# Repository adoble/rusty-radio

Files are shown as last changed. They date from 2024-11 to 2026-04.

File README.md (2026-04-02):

# Rusty Radio

An embedded internet radio written in Rust.

> **⚠️ Work In Progress**
>
> This project is under active development. Features, hardware, and software may change frequently. 

## Supported Formats

Rusty Radio currently supports:
- MP3
- AAC
- M3U

## System Diagram



## Hardware
 - For the radio uses the Seeed Studio [XIAO ESP32C-C3](https://wiki.seeedstudio.com/XIAO_ESP32C3_Getting_Started/) for its external antenna, making the radio independent of the enclosure.
 - For the user interface (display, tuning knob and preset buttons) uses another XIAO ESP32-C3 which communicates over an UART interface with the radio processor. 
   This approach was chosen as using C3 (or for that matter, a S3) for both the radio and the display led to memory issues.  
- Uses the VS1053 chip to decode the streamed audio.
- Schematics are created using KiCad 9.0.

## Software Architecture

- Built with `esp-hal` and [Embassy](https://dev.to/theembeddedrustacean/embassy-on-esp-getting-started-27fi) for async task scheduling.
- Project scaffolded using `cargo generate esp-rs/esp-template`. See the [GitHub repo](https://github.com/esp-rs/esp-template). The software project root is `controller`.

## Development Notes

- Embassy code examples are referenced from [esp-hal examples](https://github.com/esp-rs/esp-hal/tree/main/examples/src/bin).
- For more on Embassy, see the [Embassy Book](https://embassy.dev/book/).

---

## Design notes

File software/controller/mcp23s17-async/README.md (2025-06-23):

# Async MCP23S17 driver





An asynchronous driver for the MCP23S17 I/O expander which is accessed over an SPI bus.

## Example usage

```rs
// spi_device implements the SpiDevice trait from embedded_hal_async >= 1.0.0
// The hardware address corresponds to the way the pins A0, A1, A2 are physically connected
let mut mcp23s17 = mcp23s17_async::Mcp23s17::new(spi_device, 0b000).await.ok().unwrap();

// Configure pin GPA0 as an output
mcp23s17.pin_mode(0, mcp23s17_async::PinMode::Output).await.ok().unwrap();
// Set pin GPA0 high
mcp23s17.set_high(0);

// Configure pin GPA1 as an pullup input
mcp23s17.pin_mode(1, mcp23s17_async::PinMode::InputPullup).await.ok().unwrap();
// Read GPA1's level
let is_high = mcp23s17.read(1).await.ok().unwrap();
```

## Example implementation of the SpiDevice trait

```rs
// Assuming the SpiBus trait is implemented for Spi

spi_device = MySpiDevice::new(spi, cs);

struct MySpiDevice {
    spi: Spi,
    cs: SpiCsPin,
}

impl MySpiDevice{
    fn new(spi: Spi, mut cs: SpiCsPin) -> MySpiDevice {
        // IMPORTANT, otherwise MCP23S17 might not work
        cs.set_high();

        MySpiDevice { spi, cs }
    }
}

impl embedded_hal_async::spi::SpiDevice for MySpiDevice {
    async fn transaction(
        &mut self,
        operations: &mut [embedded_hal_async::spi::Operation<'_, u8>],
    ) -> Result<(), Self::Error> {  
        for operation in operations {
            match operation {
                embedded_hal_async::spi::Operation::DelayNs(_) => {}
                _ => {
                    self.cs.set_low();
                }
            }
            match operation {
                embedded_hal_async::spi::Operation::Read(words) => {
                    let _ = embedded_hal_async::spi::SpiBus::read(&mut self.spi, words).await;
                }
                embedded_hal_async::spi::Operation::Write(words) => {
                    let _ = embedded_hal_async::spi::SpiBus::write(&mut self.spi, words).await;
                }
                embedded_hal_async::spi::Operation::Transfer(read, write) => {
                    let _ = embedded_hal_async::spi::SpiBus::transfer(&mut self.spi, read, write).await;
                }
                embedded_hal_async::spi::Operation::TransferInPlace(words) => {
                    let _ = embedded_hal_async::spi::SpiBus::transfer_in_place(&mut self.spi, words).await;
                }
                embedded_hal_async::spi::Operation::DelayNs(ns) => {
                    delay_us(*ns / 1000).await;
                }
            }
            match operation {
                embedded_hal_async::spi::Operation::DelayNs(_) => {}
                _ => {
                    self.cs.set_high();
                }
            }                   
        }
        Ok(())
    }
}

impl embedded_hal_async::spi::ErrorType for MySpiDevice {
    type Error = Infallible;
}

impl core::fmt::Debug for MySpiDevice {
    fn fmt(&self, f: &mut core::fmt::Formatter<'_>) -> core::fmt::Result {
        write!(f, "MySpi")
    }
}
```

## Acknowledgements

Many of the documentation comments in this library are taken direct from the
[MCP23S17 datasheet](https://www.microchip.com/en-us/product/MCP23S17) and are
© 2005-2022 Microchip Technology Inc. and its subsidiaries.

Inspired by this [Arduino MCP23S17 Library](https://github.com/dreamcat4/Mcp23s17)
and the [RPPAL MCP23S17 Library](https://github.com/solimike/rppal-mcp23s17/)

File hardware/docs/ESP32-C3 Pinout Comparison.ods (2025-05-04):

Rusty Radio
Signal | ESP32-C3-DevKit-M1 |  | XIAO ESP32C3
 | Pins used |  |  |  | Maybe use
 | GPIO | 1 | GPIO | !!! | 3
 | GPIO | 2 |  | 2
 | GPIO
 | GPIO | 5 |  | 5
 | GPIO | 6 |  | 6
 | GPIO | 7 |  | 7
 | GPIO | 8 |  | 8
 | GPIO | 9 |  | 9
 | GPIO | 10 |  | 10
 | GPIO | 20 |  | !!! | 4

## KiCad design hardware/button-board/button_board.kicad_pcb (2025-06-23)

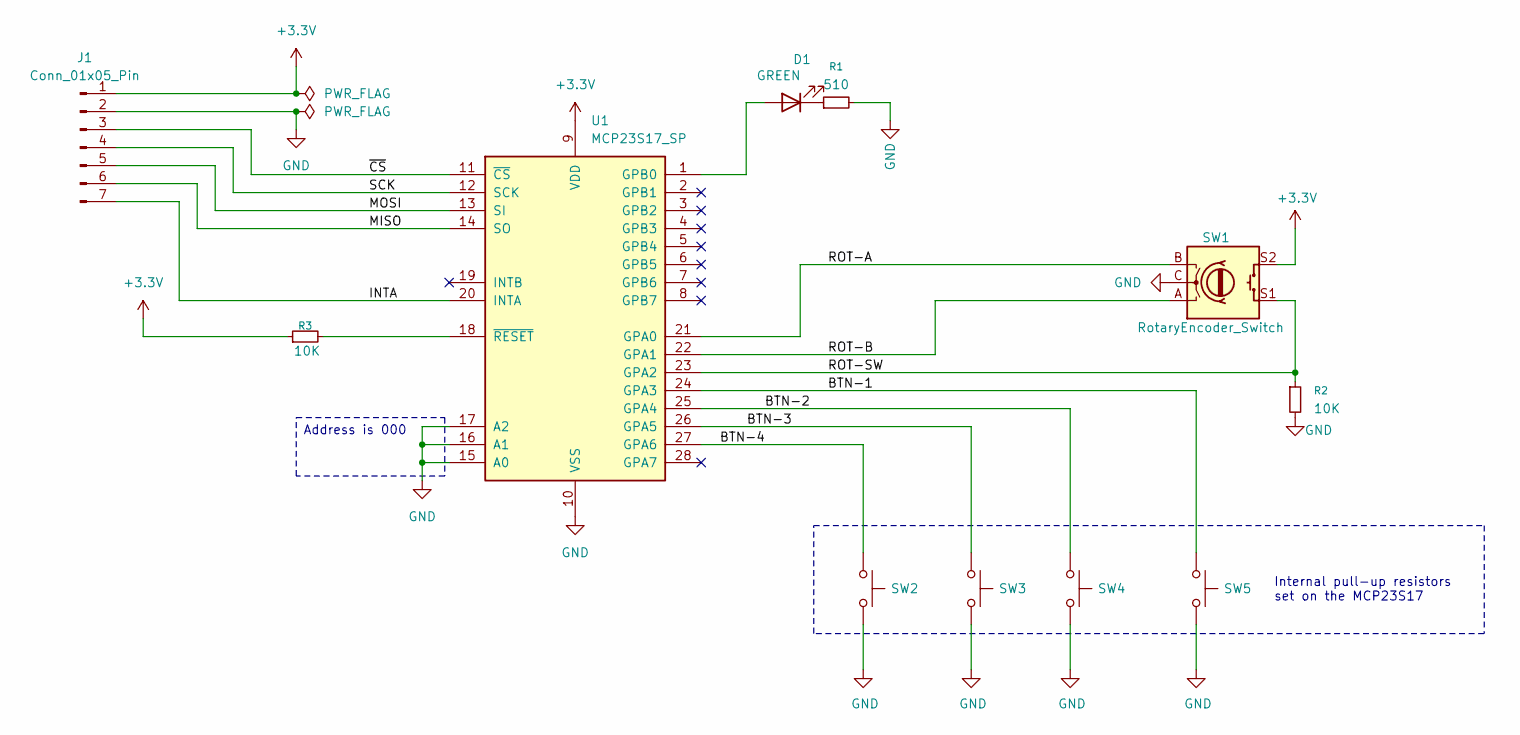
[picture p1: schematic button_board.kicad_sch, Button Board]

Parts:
D1: GREEN; D_T-1_P2.54mm_Vertical_AnodeUp
J1: Conn_01x05_Pin; PinHeader_1x07_P2.54mm_Vertical
R1: 510; R_Axial_DIN0207_L6.3mm_D2.5mm_P5.08mm_Vertical
R2, R3: 10K; R_Axial_DIN0207_L6.3mm_D2.5mm_P5.08mm_Vertical
SW1: RotaryEncoder_Switch; RotaryEncoder_Alps_EC11E-Switch_Vertical_H20mm
SW2, SW3, SW4, SW5: SW_Push; SW_Tactile_Straight_KSA0Axx1LFTR
U1: MCP23S17_SP; DIP-28_W7.62mm

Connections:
+3.3V: J1.1, R3.1, SW1.S2, U1.9 (VDD)
/BTN-1: SW5.1, U1.24 (GPA3)
/BTN-2: SW4.1, U1.25 (GPA4)
/BTN-3: SW3.1, U1.26 (GPA5)
/BTN-4: SW2.1, U1.27 (GPA6)
/INTA: J1.7, U1.20 (INTA)
/MISO: J1.6, U1.14 (SO)
/MOSI: J1.5, U1.13 (SI)
/ROT-A: SW1.B, U1.21 (GPA0)
/ROT-B: SW1.A, U1.22 (GPA1)
/ROT-SW: R2.1, SW1.S1, U1.23 (GPA2)
/SCK: J1.4, U1.12 (SCK)
/~CS: J1.3, U1.11 (~CS)
GND: J1.2, R1.2, R2.2, SW1.C, SW2.2, SW3.2, SW4.2, SW5.2, U1.10 (VSS), U1.15 (A0), U1.16 (A1), U1.17 (A2)
unnamed: D1.2 (A), U1.1 (GPB0)
unnamed: D1.1 (K), R1.1
unnamed: R3.2, U1.18 (~RESET)

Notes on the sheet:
Internal pull-up resistors set on the MCP23S17
Address is 000

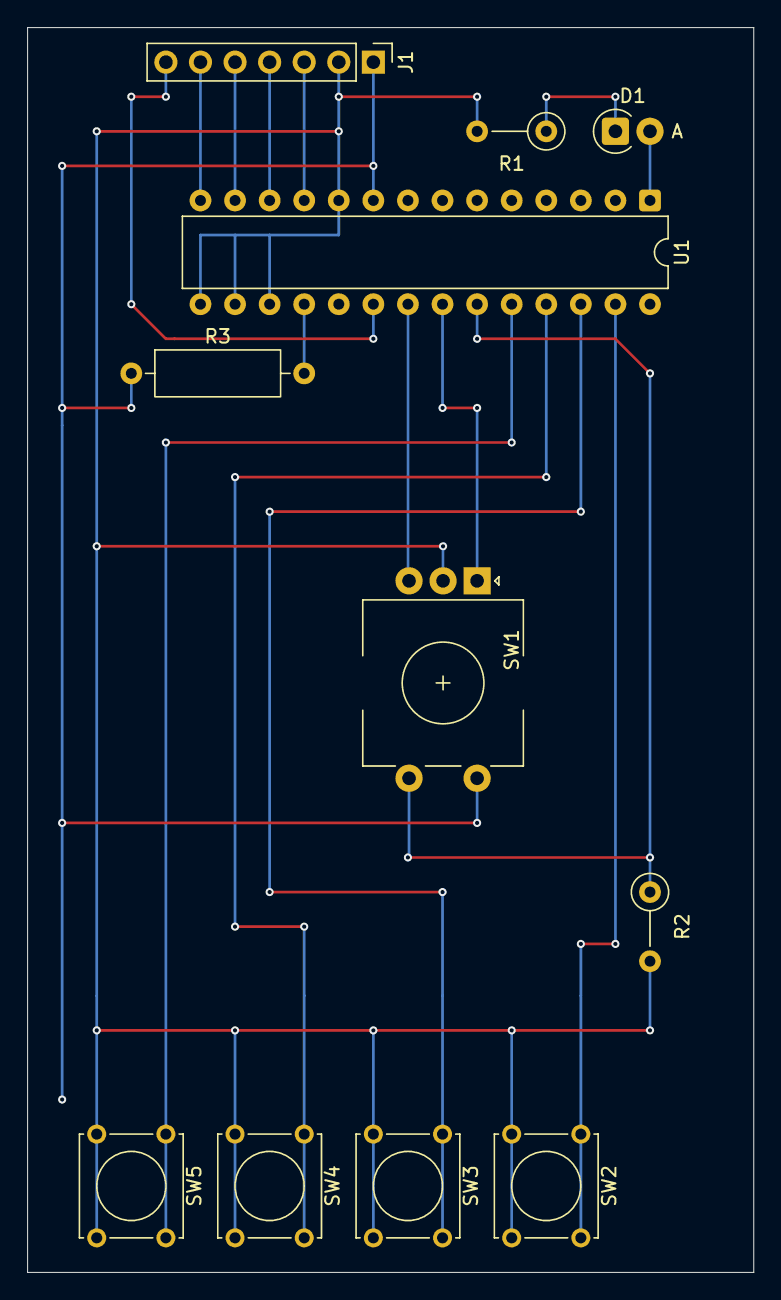
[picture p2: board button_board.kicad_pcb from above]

Board: 2 copper layers, 53.3 x 91.4 mm, 11 parts (0 on the bottom side), 17 nets.

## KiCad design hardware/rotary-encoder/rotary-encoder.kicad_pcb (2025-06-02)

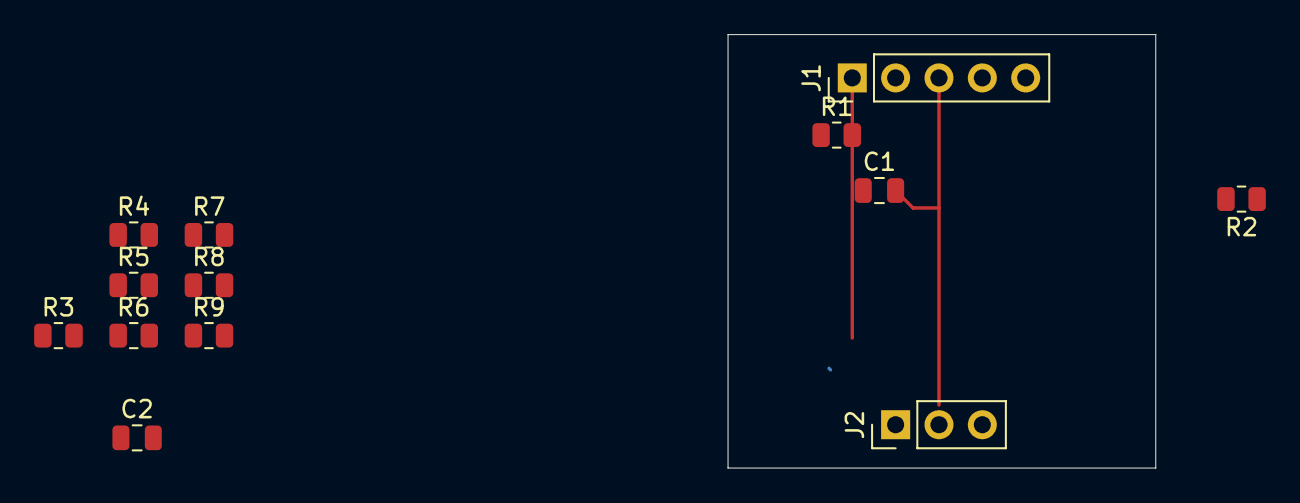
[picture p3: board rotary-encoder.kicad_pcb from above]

Board: 2 copper layers, 25.1 x 25.4 mm, 13 parts (0 on the bottom side), 9 nets.

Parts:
C1, C2: 10n; C_0805_2012Metric
J1: Conn_01x05; PinHeader_1x05_P2.54mm_Vertical
J2: Conn_01x03; PinHeader_1x03_P2.54mm_Vertical
R1, R2: 1k; R_0805_2012Metric
R3, R4, R5, R6, R7, R8, R9: 100K; R_0805_2012Metric

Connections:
+3.3V: J2.1, R1.1, R2.1
GND: C1.2, C2.2, J1.3, J2.3, R7.1
unnamed: C1.1, J1.1, R1.2, R3.1
unnamed: C2.1, J1.5, R2.2, R4.1
unnamed: R3.2, R5.1
unnamed: R4.2, R6.1
unnamed: R5.2, R8.2, R9.1
unnamed: R7.2, R8.1
OUT: J2.2, R6.2, R9.2

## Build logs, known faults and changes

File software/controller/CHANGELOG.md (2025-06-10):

# Changelog
All notable changes to the Rusty Radio Controller project will be documented in this file.

The format is based on [Keep a Changelog](https://keepachangelog.com/en/1.0.0/),
and this project adheres to [Semantic Versioning](https://semver.org/spec/v2.0.0.html).

## [0.0.5]

### Added 

- User agent derived from manifest file. 

## [0.0.4]

### Added

- Significant code changes to allow more than one station to be tuned.

## [0.0.3]

Proof of concept version. 

### Changed
- Switch target board from ESP32-C3-DevKit_M to Seeed XIAO ESP32C3 to generic ESP32-C3
- Update esp-hal dependencies to v0.23.1
- Fix esp-alloc dependency to use stable version

### Performance
- Optimize WiFi configuration:
  - RX queue size increased to 20
  - TX queue size set to 5
  - Dynamic RX/TX buffer numbers set to 16
  - Enable AMPDU for both RX and TX
  - Set RX BA window to 6
  - Set max burst size to 8
- Build optimizations:
  - Enable LTO (Link Time Optimization)
  - Set optimization level to 3 for speed

### Added
- Configuration for WiFi buffer tuning
- Performance monitoring for streaming

### Fixed
- Download speed was too slow for internet radio
- ESP-alloc dependency issues
- Build configuration for release mode

### Known Issues
- This currently only plays one station and nothing much else!

## [0.0.2] - 2025-05-12

### Added
- Initial implementation of internet radio streaming
- Basic VS1053 codec driver support
- WiFi connectivity
- Audio streaming pipeline

[Unreleased]: https://github.com/adoble/rusty-radio/compare/v0.0.2...HEAD
[0.0.2]: https://github.com/adoble/rusty-radio/releases/tag/v0.0.2

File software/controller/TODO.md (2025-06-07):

### TODO 

- [ ] Cycling through stations does the first station more then once
- [ ] Need to test with a station that uses extended M3U 
- [x] refactor: Move the stations logic into the tuner task. 
- [ ] use case: Add a rotary controller to change stations 
- [ ] When changing stations there a a burst of "noise". Suspend play_music task for a bit to remove this. 
- [ ] Move the performance statistics code into a cfg section. Note: this is more challenging than thought.
- [ ] Get the program name and version for the HTTP User Agent from the Cargo.toml file
- [ ] Would be good to have a mute button, especially during development
- [ ] Look into using the radio-browser. See https://gitlab.com/radiobrowser/radiobrowser-api-rust

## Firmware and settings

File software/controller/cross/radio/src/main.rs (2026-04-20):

#![cfg_attr(not(test), no_std)]
#![no_main]

//! An internet radio
//!

// [ ] Check out this about assigning resouces and rewriting initialized_peripherals.rs:
//      https://github.com/embassy-rs/embassy/blob/main/examples/rp/src/bin/assign_resources.rs

// See this about having functions to setup the peripherals and avoid the borrow problem:
// https://users.rust-lang.org/t/how-to-borrow-peripherals-struct/83565/2

// See rust-projects/edge-http-embassy-esp for how to access a web page using DNS.

mod async_delay;
mod constants;

use constants::{MULTIPLEXER_DEVICE_ADDR, NUMBER_SOCKETS_STACK_RESOURCES};

mod hardware;
use hardware::Hardware;

mod task;
use task::{
    play_music::play_music,
    radio_stations::radio_stations,
    receive_radio_control_commands::receive_radio_control_commands,
    //station_indicator::station_indicator,
    //read_test_music::read_test_music,
    stream::stream,
    //stream2::stream2,
    sync::CODEC_DRIVER,
    sync::MULTIPLEXER_DRIVER,
    sync::STATION_CHANGE_WATCH,

    //access_radio_stations::access_radio_stations,
    //tuner::tuner,
    //wifi_connected_indicator::wifi_connected_indicator,
    wifi_tasks::{run_network_stack, wifi_connect},
};

use radio_control_protocol::{Command, RadioControlProtocol};
// mod radio_stations;
// use radio_stations::radio_stations;

mod front_panel;
use front_panel::FrontPanel;

mod sendable_multiplexer_driver;
use sendable_multiplexer_driver::SendableMultiplexerDriver;

//use stations::{Station, Stations};

// External crates
//use esp_backtrace as _;
use esp_hal::{
    clock::CpuClock,
    gpio::{Input, Output},
    ram,
    spi::master::{Config as SpiConfig, Spi},
    time::Rate,
};

use embassy_executor::Spawner;

use embassy_embedded_hal::shared_bus::asynch::spi::SpiDeviceWithConfig;
//use embassy_embedded_hal::shared_bus::blocking::spi::SpiDeviceWithConfig as BlockingSpiDeviceWithConfig;

use embassy_sync::{blocking_mutex::raw::CriticalSectionRawMutex, mutex::Mutex};

use static_cell::StaticCell;

use async_delay::AsyncDelay;

static_assertions::const_assert!(true);

use vs1053_driver::Vs1053Driver;

use mcp23s17_async::Mcp23s17;

// use ra8875::RA8875;

use esp_println::println;

use esp_alloc as _;

use crate::{constants::STATIONS_URL, hardware::WifiHardware};

static STACK: StaticCell<embassy_net::Stack> = StaticCell::new();

static FRONT_PANEL: StaticCell<FrontPanel> = StaticCell::new();

type SharedSpiBus = Mutex<CriticalSectionRawMutex, Spi<'static, esp_hal::Async>>;

// type MultiplexerDriverType<'a> =
//     SpiDeviceWithConfig<'a, CriticalSectionRawMutex, Spi<'a, esp_hal::Async>, Output<'a>>;

type Vs1053DriverType<'a> = Vs1053Driver<
    SpiDeviceWithConfig<'a, CriticalSectionRawMutex, Spi<'a, esp_hal::Async>, Output<'a>>,
    Input<'a>,
    Output<'a>,
    AsyncDelay,
>;

pub type MultiplexerDriverType<'a> =
    Mcp23s17<SpiDeviceWithConfig<'a, CriticalSectionRawMutex, Spi<'a, esp_hal::Async>, Output<'a>>>;

#[panic_handler]
fn panic(_: &core::panic::PanicInfo) -> ! {
    loop {}
}

esp_bootloader_esp_idf::esp_app_desc!();

// #[esp_hal_embassy::main]
#[esp_rtos::main]
async fn main(spawner: Spawner) {
    esp_println::println!("INFO: Rusty Radio started");

    let config = esp_hal::Config::default().with_cpu_clock(CpuClock::max());
    let peripherals = esp_hal::init(config);

    // See this: https://github.com/esp-rs/esp-hal/blob/v0.21.1/esp-wifi/MIGRATING-0.9.md#memory-allocation
    // Size has been empirically determined.
    // esp_alloc::heap_allocator!(size: 48 * 1024); //Recommended
    esp_alloc::heap_allocator!(size: 76 * 1024);
    //    esp_alloc::heap_allocator!(#[ram(reclaimed)] size: 64 * 1024);
    //esp_alloc::heap_allocator!(#[ram(reclaimed)] size: 64 * 1024);
    // For the S3
    // esp_alloc::heap_allocator!(size: 64 * 1024);

    // Initialise gpio ,spi and wifi peripherals. The initialised peripherals are then fields in the hardware struct
    // and are given symbolic names.
    let hardware = Hardware::init::<NUMBER_SOCKETS_STACK_RESOURCES>(peripherals);

    let delay = AsyncDelay::new();

    // Initialise the schedular (in this case embasssy).
    // This needs to be done before initialiing the wifi
    esp_rtos::start(hardware.system_timer.alarm0, hardware.software_interrupt0);
    //esp_rtos::start(hardware.system_timer.alarm0);

    let wifi_hardware =
        WifiHardware::init_wifi::<NUMBER_SOCKETS_STACK_RESOURCES>(hardware.wifi, hardware.rng);

    // The stack needs to be static so that it can be used in tasks.
    STACK.init(wifi_hardware.sta_stack);

    // Need to convert the spi driver into an static blocking async version so that if can be accepted
    // by vs1053_driver::Vs1052Driver (which takes embedded_hal_async::spi::SpiDevice)
    static SPI_BUS: StaticCell<SharedSpiBus> = StaticCell::new();
    let spi_bus = SPI_BUS.init(Mutex::new(hardware.spi_bus));

    /*
       ---------------------------
       Setup the VS1053 MP3 codec
       ---------------------------
    */
    // Init the vs1053 spi speeds
    // spi_sci_config.frequency = Rate::from_khz(250); //250.kHz();
    let spi_sci_config = SpiConfig::default().with_frequency(Rate::from_khz(250));

    // spi_sdi_config.frequency = Rate::from_khz(8000); //  8000.kHz();
    let spi_sdi_config = SpiConfig::default().with_frequency(Rate::from_khz(8000));

    let spi_sci_device = SpiDeviceWithConfig::new(spi_bus, hardware.xcs, spi_sci_config);
    let spi_sdi_device = SpiDeviceWithConfig::new(spi_bus, hardware.xdcs, spi_sdi_config);

    let vs1053_driver: Vs1053DriverType = Vs1053Driver::new(
        spi_sci_device,
        spi_sdi_device,
        hardware.dreq,
        hardware.reset_codec,
        delay,
    )
    .unwrap();

    // Setup the mutex for the vs1053 driver and then initialise the chip.
    {
        *(CODEC_DRIVER.lock().await) = Some(vs1053_driver);
        let mut driver_unlocked = CODEC_DRIVER.lock().await;
        if let Some(driver) = driver_unlocked.as_mut() {
            driver.begin().await.unwrap();
        }
    }

    // Setup spi for the front panel controller
    // Altough the mutiplexer SPI speed can go up to 10MHz, using a lower frequency works just fine
    // (and gives less problems with transmission lines effects on the breadboard).
    // let spi_multiplexer_config = SpiConfig::default().with_frequency(Rate::from_mhz(1));

    // let spi_multiplexer_device: SpiDeviceWithConfig<
    //     '_,
    //     CriticalSectionRawMutex,
    //     Spi<'_, esp_hal::Async>,
    //     Output<'_>,
    // > = SpiDeviceWithConfig::new(spi_bus, hardware.mux_cs, spi_multiplexer_config);

    // Set up the mutiplexer driver and provide a mutex for it. Using the sendable version.
    // let multiplexer_driver: SendableMultiplexerDriver = SendableMultiplexerDriver(
    //     Mcp23s17::new(spi_multiplexer_device, MULTIPLEXER_DEVICE_ADDR)
    //         .await
    //         .unwrap(),
    // );
    // {
    //     *(MULTIPLEXER_DRIVER.lock().await) = Some(multiplexer_driver);
    // }

    // Set up the mutiplexer driver and provide a mutex for it.
    // let multiplexer_driver: Mcp23s17<
    //     SpiDeviceWithConfig<'_, CriticalSectionRawMutex, Spi<'_, esp_hal::Async>, Output<'_>>,
    // > = Mcp23s17::new(spi_multiplexer_device, MULTIPLEXER_DEVICE_ADDR)
    //     .await
    //     .unwrap();
    // {
    //     *(MULTIPLEXER_DRIVER.lock().await) = Some(multiplexer_driver);
    // }

    // Initalise the front panel containing the controls
    // let front_panel = FrontPanel::new()
    //     .await
    //     .expect("ERROR: Cannot initialise front panel");

    // let front_panel = FRONT_PANEL.init(front_panel);

    // set up the stations

    // let stations_data = include_bytes!("../../../resources/stations.txt");

    // let stations = RadioStations::load(stations_data).expect("ERROR: Cannot load stations");
    // let stations = RADIO_STATIONS.init(stations);

    // Print the registers using the shared driver for the vs1053
    //print_registers().await;

    // TODO set these to must_spawn

    // Setting up the network
    spawner
        .spawn(wifi_connect(wifi_hardware.wifi_controller))
        .ok();
    spawner.spawn(run_network_stack(wifi_hardware.runner)).ok();

    // Check that the link signal is present and the stack has a valid IP config
    // before continuing.
    wifi_hardware.sta_stack.wait_link_up().await;
    wifi_hardware.sta_stack.wait_config_up().await;

    // // Read the stations from the internet
    // let stations = read_stations(hardware.sta_stack, constants::STATIONS_URL)
    //     .await
    //     .expect("ERROR: Unable to read stations list");

    // Read the stations from the stations list in the internet and set up the tuner task
    // let r = spawner.spawn(radio_stations(
    //     spawner,
    //     wifi_hardware.sta_stack,
    //     front_panel,
    //     STATIONS_URL,
    // ));
    // match r {
    //     Ok(_) => esp_println::println!("DEBUG: radio_stations spawn successful"),
    //     Err(e) => esp_println::println!("DEBUG: radio spawn error:{:?}", e),
    // }
    // spawner
    //     .spawn(radio_stations(
    //         spawner,
    //         wifi_hardware.sta_stack,
    //         front_panel,
    //         STATIONS_URL,
    //     ))
    //     .ok();

    // Note that this also signals the initial station to other tasks.
    spawner
        .spawn(radio_stations(
            spawner,
            wifi_hardware.sta_stack,
            STATIONS_URL,
        ))
        .ok();

    // Tasks to handle peripherals
    //spawner.spawn(tuner(hardware.button_pin)).ok();
    // spawner
    //     .spawn(tuner(stations, front_panel, hardware.intr))
    //     .ok();

    // spawner
    //     .spawn(tuner(stations, front_panel, hardware.intr))
    //     .ok();

    //spawner.spawn(wifi_connected_indicator(hardware.led)).ok();

    // Streaming and playing music
    // spawner.spawn(stream(wifi_hardware.sta_stack)).ok();
    spawner.spawn(stream(wifi_hardware.sta_stack)).ok();

    spawner.spawn(play_music()).ok();

    // Showing on the panel LED when a station has been tuned in
    // TODO This is a temporary solution until the display is ready.
    //spawner.spawn(station_indicator(front_panel)).ok();
}

// async fn print_registers() {
//     let mut driver_unlocked = CODEC_DRIVER.lock().await;
//     if let Some(driver) = driver_unlocked.as_mut() {
//         // Set the volume so we can see the value when we dump the registers
//         let left_vol = 0x11;
//         let right_vol = 0x22;

//         driver.set_volume(left_vol, right_vol).await.unwrap();
//         // Should see 1122 as the vol reg
//         let registers = driver.dump_registers().await.unwrap();

//         esp_println::println!("Dumped registers:");
//         esp_println::println!("mode: {:X}", registers.mode);
//         esp_println::println!("status: {:X}", registers.status);
//         esp_println::println!("clockf: {:X}", registers.clock_f);
//         esp_println::println!("volume: {:X}", registers.volume);
//         esp_println::println!("audio_data : {:X}", registers.audio_data);
//     } else {
//         esp_println::println!("ERROR: Could not print registers");
//     }
// }

#[derive(Debug, Clone, PartialEq)]
pub enum DisplayError {
    /// Error from the display driver itself
    DriverError,
    /// Drawing operation failed
    DrawingError,
    /// Display initialization failed
    InitializationError,
    /// Display communication error (I2C, SPI, etc.)
    CommunicationError,
    /// Display is not ready or in wrong state
    NotReady,
    /// Invalid coordinates or size
    InvalidDimensions {
        x: i32,
        y: i32,
        width: u32,
        height: u32,
    },
    /// Color conversion error
    ColorError,
    /// Generic error with message
    Other,
}

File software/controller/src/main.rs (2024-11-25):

//! An internet radio

#![no_std]
#![no_main]

use core::str::from_utf8;

use embassy_executor::Spawner;
use embassy_net::dns::DnsSocket;
use embassy_net::tcp::client::{TcpClient, TcpClientState};
use embassy_net::Stack;
use embassy_sync::blocking_mutex::raw::CriticalSectionRawMutex;
//use embassy_sync::blocking_mutex::CriticalSectionMutex;
use embassy_sync::channel::Channel;
use embassy_sync::signal;
use embassy_sync::{blocking_mutex, mutex};
use embassy_time::{Duration, Timer};
use esp_backtrace as _;
//use esp_hal::gpio::{AnyPin, Input, Io, Level, Output, Pull};
use esp_hal::gpio::{AnyPin, Input, Io, Pull};
use esp_hal::spi::master::Spi;
use esp_hal::spi::{FullDuplexMode, SpiMode};
use esp_hal::timer::timg::TimerGroup;

use esp_hal::{prelude::*, rng::Rng};

use embedded_io_async::Read;
use esp_wifi::wifi::{WifiController, WifiDevice};
use esp_wifi::{
    init,
    wifi::{AuthMethod, ClientConfiguration, Configuration, WifiStaDevice},
    EspWifiInitFor,
};
use reqwless::client::HttpClient;
use reqwless::request;
use static_cell::StaticCell;

use static_assertions::{self, const_assert};

static_assertions::const_assert!(true);

use vs1053_driver::Vs1053Driver;

mod vs1053_driver;

const NUMBER_SOCKETS_STACK_RESOURCES: usize = 3;
const NUMBER_SOCKETS_TCP_CLIENT_STATE: usize = 3;

// The number of sockets specified for StackResources needs to be the same or higher then the number of sockets specified
// in setting up the TcpClientState. Getting this wrong resukts in the program crashing - and took me a long time
// to figure out the cause.
// This is checked at compilation time by this macro.
// An alterantive would be to use the same constant for setting up both StackResources and TcpClientState
const_assert!(NUMBER_SOCKETS_STACK_RESOURCES >= NUMBER_SOCKETS_TCP_CLIENT_STATE);

// See https://github.com/embassy-rs/embassy/blob/main/examples/rp/src/bin/sharing.rs. Altough for the RP
// it also works for the esp32
type SpiAsyncMutex =
    mutex::Mutex<CriticalSectionRawMutex, Spi<'static, esp_hal::peripherals::SPI2, FullDuplexMode>>;

//const NUMBER_SOCKETS: usize = 3; // Used by more than one package and needs to be in sync

static RESOURCES: StaticCell<embassy_net::StackResources<NUMBER_SOCKETS_STACK_RESOURCES>> =
    StaticCell::new();
static STACK: StaticCell<embassy_net::Stack<WifiDevice<WifiStaDevice>>> = StaticCell::new();

// Signal that the web should be accessed
static ACCESS_WEB_SIGNAL: signal::Signal<CriticalSectionRawMutex, bool> = signal::Signal::new();

static CHANNEL: Channel<CriticalSectionRawMutex, [u8; 32], 64> = Channel::new();

static TEST_MUSIC: &[u8; 55302] = include_bytes!("../resources/music-16b-2c-8000hz.mp3");

const SSID: &str = env!("WLAN-SSID");
const PASSWORD: &str = env!("WLAN-PASSWORD");

const DEBOUNCE_DURATION: u64 = 100; // Milliseconds  TODO use fugit?

#[embassy_executor::task]
async fn button_monitor(mut pin: Input<'static, AnyPin>) {
    loop {
        pin.wait_for_falling_edge().await;

        // Debounce
        // TODO see also https://github.com/embassy-rs/embassy/blob/main/examples/rp/src/bin/debounce.rs
        Timer::after(Duration::from_millis(DEBOUNCE_DURATION)).await;

        if pin.is_low() {
            // Pin is still low so acknowledge
            esp_println::println!("Button pressed after debounce!");

            // Now access the web by sending a signal
            ACCESS_WEB_SIGNAL.signal(true)
        }
    }
}

// const BUFFER_SIZE: usize = 8192;
const BUFFER_SIZE: usize = 2560;

/// This task only accesses the web when  ACCESS_WEB_SIGNAL is signalled.
#[embassy_executor::task]
async fn access_web(stack: &'static Stack<WifiDevice<'static, WifiStaDevice>>) {
    let mut rx_buffer = [0; BUFFER_SIZE];

    loop {
        ACCESS_WEB_SIGNAL.wait().await;

        esp_println::println!("Access web task");

        loop {
            if stack.is_link_up() {
                break;
            }
            Timer::after(Duration::from_millis(500)).await;
        }

        let client_state =
            TcpClientState::<NUMBER_SOCKETS_TCP_CLIENT_STATE, BUFFER_SIZE, BUFFER_SIZE>::new();
        let tcp_client = TcpClient::new(stack, &client_state);
        let dns = DnsSocket::new(&stack);
        let mut http_client = HttpClient::new(&tcp_client, &dns);

        esp_println::println!("Setting up request");

        let mut request = http_client
            .request(
                request::Method::GET,
                "http://andrew-doble.hier-im-netz.de/ir/stations.txt",
            )
            .await
            .unwrap();

        esp_println::println!("Sending request, reading response");
        let response = request.send(&mut rx_buffer).await.unwrap();

        esp_println::println!("Getting body");

        esp_println::println!("Http body:");

        // This approach can be used to read a stream
        let mut reader = response.body().reader();
        let mut small_buffer: [u8; 32] = [0; 32];

        loop {
            let res = reader.read(&mut small_buffer).await;
            match res {
                Ok(size) if size == 0 => {
                    esp_println::println!("EOF");
                    break;
                }
                Ok(size) if size > 0 => {
                    //let content = from_utf8(&small_buffer).unwrap();
                    //esp_println::print!("{content}");
                    CHANNEL.send(small_buffer).await;
                    continue;
                }
                Err(err) => {
                    esp_println::println!("Error in reading {:?}", err);
                    break;
                }
                _ => {
                    esp_println::println!("Unknown read condition");
                    break;
                }
            }
        }

        // This approach is better to read a page (for instance, the stations list)
        // let body = from_utf8(response.body().read_to_end().await.unwrap()).unwrap();
        // esp_println::println!("Http body:");
        // esp_println::println!("{body}");

        ACCESS_WEB_SIGNAL.reset();

        // ???
        //Timer::after(Duration::from_millis(3000)).await;
    }
}

#[embassy_executor::task]
async fn process_channel() {
    loop {
        let data = CHANNEL.receive().await;
        let content = from_utf8(&data).unwrap();
        esp_println::print!("{content}");
    }
}

#[embassy_executor::task]
async fn notification_task() {
    loop {
        esp_println::println!("Press button to access web page!");
        Timer::after(Duration::from_millis(3_000)).await;
    }
}
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

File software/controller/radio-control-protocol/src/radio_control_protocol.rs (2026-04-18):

use embedded_hal_nb::serial::{Error, Read, Write}; // Import the Write trait
use heapless::{String, Vec};
use itoa::Buffer;

use crate::uart_handler::{UartHandler, UartHandlerError, command::Command};

const MAX_NUMBER_PARAMETERS: usize = 5;

pub const MAX_PARAMETER_LEN: usize = 40;

pub struct RadioControlProtocol<'a, S>
where
    S: Write<u8> + Read<u8>,
{
    uart_handler: UartHandler<'a, S, MAX_PARAMETER_LEN, MAX_NUMBER_PARAMETERS>,
}

impl<'a, S> RadioControlProtocol<'a, S>
where
    S: Write<u8> + Read<u8>,
{
    pub fn new(serial: &'a mut S) -> Self {
        let uart_handler = UartHandler::new(serial);
        Self { uart_handler }
    }

    /// Sets a radio station based on it's id. The radio station name is returned.
    pub fn set_station(
        &mut self,
        station_id: u8,
    ) -> Result<String<MAX_PARAMETER_LEN>, RadioControlProtocolError> {
        let cmd = Command::Station;
        let mut tx_parameters = Vec::<&str, 5>::new();

        let mut buffer = Buffer::new();
        let station_id_str = buffer.format(station_id);

        // SAFETY - Ony ever pushing one parameter.
        tx_parameters.push(station_id_str).unwrap();

        self.uart_handler
            .send_command(cmd, tx_parameters)
            .map_err(|e| UartHandlerError::SerialWrite(e.kind()))?;

        let mut rx_parameters: Vec<String<MAX_PARAMETER_LEN>, MAX_NUMBER_PARAMETERS> = Vec::new();

        self.uart_handler.receive_response(&mut rx_parameters)?;

        if !rx_parameters.is_empty() {
            Ok(rx_parameters[0].clone())
        } else {
            Err(RadioControlProtocolError::StationNameNotReceived)
        }
    }

    /// Sets a station based its preset id. The station name is returned.
    pub fn set_preset(
        &mut self,
        preset_id: u8,
    ) -> Result<String<MAX_PARAMETER_LEN>, RadioControlProtocolError> {
        let cmd = Command::Preset;
        let mut tx_parameters = Vec::<&str, 5>::new();

        let mut buffer = Buffer::new();
        let preset_id_str = buffer.format(preset_id);

        // SAFETY - Only ever pushing one parameter.
        tx_parameters.push(preset_id_str).unwrap();

        self.uart_handler
            .send_command(cmd, tx_parameters)
            .map_err(|e| UartHandlerError::SerialWrite(e.kind()))?;

        let mut rx_parameters: Vec<String<MAX_PARAMETER_LEN>, MAX_NUMBER_PARAMETERS> = Vec::new();

        self.uart_handler.receive_response(&mut rx_parameters)?;

        if !rx_parameters.is_empty() {
            Ok(rx_parameters[0].clone())
        } else {
            Err(RadioControlProtocolError::StationNameNotReceived)
        }
    }

    /// Sets a station based its preset id. The station name is returned.
    pub fn query_config(&mut self) -> Result<usize, RadioControlProtocolError> {
        let cmd = Command::Config;
        let tx_parameters = Vec::<&str, 5>::new();

        // let mut buffer = Buffer::new();
        // let preset_id_str = buffer.format(preset_id);

        // SAFETY - Only ever pushing one parameter.
        // tx_parameters.push(preset_id_str).unwrap();

        self.uart_handler
            .send_command(cmd, tx_parameters)
            .map_err(|e| UartHandlerError::SerialWrite(e.kind()))?;

        let mut rx_parameters: Vec<String<MAX_PARAMETER_LEN>, MAX_NUMBER_PARAMETERS> = Vec::new();

        self.uart_handler.receive_response(&mut rx_parameters)?;

        if !rx_parameters.is_empty() {
            let number_stations: usize = rx_parameters[0]
                .parse()
                .map_err(|_| RadioControlProtocolError::ParseParameter)?;

            Ok(number_stations)
        } else {
            Err(RadioControlProtocolError::IncorrectNumberParametersReturned)
        }
    }
}

#[derive(PartialEq, Debug)]
pub enum RadioControlProtocolError {
    Uart(UartHandlerError),
    StationNameNotReceived,
    ParseParameter,
    IncorrectNumberParametersReturned,
}

impl From<UartHandlerError> for RadioControlProtocolError {
    fn from(error: UartHandlerError) -> Self {
        RadioControlProtocolError::Uart(error)
    }
}

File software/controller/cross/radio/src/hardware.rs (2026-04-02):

//use embassy_time::Timer;
/// The contains the initialised peripherals used by the system.
// Based on https://users.rust-lang.org/t/how-to-borrow-peripherals-struct/83565/3
use esp_hal::{
    gpio::{Input, InputConfig, Level, Output, OutputConfig, Pull},
    interrupt::software::{SoftwareInterrupt, SoftwareInterruptControl},
    peripherals::{Peripherals, TIMG1, WIFI},
    rng::Rng,
    spi::master::{Config as SpiConfig, Spi},
    timer::{systimer::SystemTimer, timg::TimerGroup},
};

//use esp_wifi::wifi::{WifiController, WifiDevice};
use esp_radio::{
    wifi::{WifiController, WifiDevice},
    Controller,
};
// use esp_wifi::EspWifiController;

use esp_println::println;

use embassy_net::{Runner, Stack};

use static_cell::StaticCell;

use crate::constants::NUMBER_SOCKETS_STACK_RESOURCES;

//static ESP_WIFI_CONTROLLER: StaticCell<EspWifiController<'static>> = StaticCell::new();
static ESP_WIFI_CONTROLLER: StaticCell<Controller<'static>> = StaticCell::new();

static RESOURCES: StaticCell<embassy_net::StackResources<NUMBER_SOCKETS_STACK_RESOURCES>> =
    StaticCell::new();

pub struct Hardware {
    //pub button_pin: Input<'static>,
    pub xcs: Output<'static>,
    pub xdcs: Output<'static>,
    pub dreq: Input<'static>,
    pub reset_codec: Output<'static>,

    pub system_timer: SystemTimer<'static>,
    pub timer_group: TimerGroup<'static, TIMG1<'static>>,
    pub rng: Rng,

    pub spi_bus: Spi<'static, esp_hal::Async>,

    pub software_interrupt0: SoftwareInterrupt<'static, 0>,
    // pub sta_stack: Stack<'static>,
    // pub runner: Runner<'static, WifiDevice<'static>>,
    // pub wifi_controller: &'static mut WifiController<'static>,
    pub wifi: WIFI<'static>,
}

impl Hardware {
    pub fn init<const NUMBER_SOCKETS_STACK_RESOURCES: usize>(peripherals: Peripherals) -> Hardware {
        // let rng = Rng::new(peripherals.RNG);
        let rng = Rng::new();

        //let wifi = peripherals.WIFI;
        //let radio_clk = peripherals.RADIO_CLK;
        let systimer = peripherals.SYSTIMER;

        let timer_group = TimerGroup::new(peripherals.TIMG1);

        // Create the SPI from the HAL. This implements SpiBus, not SpiDevice!
        // Only SPI2 is available for the ESP32-C3 - TODO is this true?
        let spi_bus: Spi<'_, esp_hal::Async> = Spi::new(peripherals.SPI2, SpiConfig::default())
            .expect("PANIC: Could not initialize SPI")
            .with_sck(peripherals.GPIO5)
            .with_mosi(peripherals.GPIO6)
            .with_miso(peripherals.GPIO7)
            .into_async();

        let output_config = OutputConfig::default();

        Hardware {
            // Pins for ESP32-C3
            xcs: Output::new(peripherals.GPIO4, Level::High, output_config),
            xdcs: Output::new(peripherals.GPIO10, Level::High, output_config),
            dreq: Input::new(
                peripherals.GPIO8,
                InputConfig::default().with_pull(Pull::None),
            ),
            //reset: Output::new(peripherals.GPIO20, Level::High, output_config),
            reset_codec: Output::new(peripherals.GPIO3, Level::High, output_config),

            // Intially set high to display the diplay.
            //disp_cs: Output::new(peripherals.GPIO8, Level::High, output_config),

            // Assuming that the interrupt signal is actively driven and not open drain.
            // intr: Input::new(
            //     peripherals.GPIO3,
            //     InputConfig::default().with_pull(Pull::None),
            // ),
            system_timer: SystemTimer::new(systimer),

            timer_group,

            rng,
            // SPI
            spi_bus,

            // Required to initialise embassy over esp-rtos
            software_interrupt0: SoftwareInterruptControl::new(peripherals.SW_INTERRUPT)
                .software_interrupt0,
            // // Peripherals required for wifi
            // sta_stack: wifi_peripherals.sta_stack,
            // runner: wifi_peripherals.runner,
            // wifi_controller: wifi_peripherals.wifi_controller,
            wifi: peripherals.WIFI,
        }
    }
}

pub struct WifiHardware {
    pub sta_stack: Stack<'static>,
    pub runner: Runner<'static, WifiDevice<'static>>,
    pub wifi_controller: &'static mut WifiController<'static>,
}

impl WifiHardware {
    // Based on the example here: https://github.com/esp-rs/esp-hal/blob/main/examples/src/bin/wifi_embassy_access_point_with_sta.rs#L301
    pub fn init_wifi<const NUMBER_SOCKETS_STACK_RESOURCES: usize>(
        wifi: WIFI<'static>,
        //radio_clk: RADIO_CLK,
        //timg: TimerGroup<'static, TIMG1>,
        rng: Rng,
    ) -> Self {
        // let esp_wifi_ctrl = ESP_WIFI_CONTROLLER.uninit().write(
        //     init(
        //         timg.timer0,
        //         //Rng::new(peripherals.RNG.clone()),
        //         rng.clone(),
        //         radio_clk,
        //     )
        //     .unwrap(),
        // );

        // let esp_wifi_ctrl =
        //     ESP_WIFI_CONTROLLER.init(esp_radio::init(timg.timer0, rng.clone()).unwrap());

        let res = esp_radio::init();

        let esp_wifi_ctrl = match res {
            Ok(controller) => ESP_WIFI_CONTROLLER.init(controller),
            Err(e) => panic!("ERROR: wifi controller not initialised: {:?}", e),
        };

        // TODO reinstate
        //let esp_wifi_ctrl = ESP_WIFI_CONTROLLER.init(esp_radio::init().unwrap());

        let (controller, interfaces) =
            esp_radio::wifi::new(esp_wifi_ctrl, wifi, Default::default()).unwrap();

        let wifi_device = interfaces.sta;

        // let (wifi_device, controller) =
        //     esp_wifi::wifi::new_with_mode(esp_wifi_ctrl, wifi, WifiStaDevice).unwrap();

        let sta_config = embassy_net::Config::dhcpv4(Default::default());

        // Random seed.
        // Taken from example line 104 https://github.com/esp-rs/esp-hal/blob/main/examples/src/bin/wifi_embassy_access_point_with_sta.rs
        let seed = ((rng.random() as u64) << 32) | rng.random() as u64;

        // Init network stacks
        let (sta_stack, sta_runner) = embassy_net::new(
            wifi_device,
            sta_config,
            RESOURCES.init(embassy_net::StackResources::new()),
            seed,
        );

        // Make the controller static
        static CONTROLLER: StaticCell<WifiController> = StaticCell::new();
        let controller = CONTROLLER.init(controller);

        Self {
            sta_stack,
            runner: sta_runner,
            wifi_controller: controller,
        }
    }
}

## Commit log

2024-11-12 Toggle pin in task
2024-11-13 Button input
2024-11-13 RGB LED
2024-11-16 Debounced button
2024-11-16 Solved problem with different embedded-nal-async
    [main.rs]
2024-11-18 Increased number of sockets
2024-11-20 Updated comment to give advice about number of sockets
2024-11-23 Schematic used for development
    [schematic.kicad_pcb, schematic.kicad_sch]
2024-11-25 Set uu SPI and mutex
2024-11-25 Skeleton VS1053 driver
2024-11-29 Added both data and control spi devices
2024-11-29 Added reset pin
2024-11-30 Added reset fucntionality and set_volume
    [lib.rs]
2024-12-04 Added button and led
    [schematic.kicad_sch]
2024-12-13 Driver basics work and use of shared-bus
2024-12-16 Changed power wiring
    [schematic.kicad_sch]
2024-12-16 Test and correct set_volume
    [lib.rs, main.rs]
2025-01-17 Updated schematic comments
    [schematic.kicad_sch]
2025-01-18 Added print_registers function
2025-01-20 Moved main to front + clippy warnings corrected
    [main.rs]
2025-01-20 Comment outt pulse_spi, spi clock observed
2025-01-20 Spi works
2025-01-21 print_registers as simple async function
2025-01-29 Kicad spurious changes
2025-04-05 Kicad migration to Linux
    [schematic.kicad_pcb, schematic.kicad_sch]
2025-04-06 Update .gitignore to ignnore KiCad temporary files
2025-04-15 Removed target-test as just giving problems
    [main.rs]
2025-04-15 Switched back to more basic http handling
2025-04-17 Correctly builds http request
    [lib.rs]
2025-04-28 Powering of the VS1053
    [schematic.kicad_sch]
2025-05-04 Schematic for XIAO version
    [ESP32-C3 Pinout Comparison.ods, schematic-xiao.kicad_pcb, schematic-xiao.kicad_sch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]
2025-05-09 New XIAO ESP32C3 schematic
    [schematic-xiao.kicad_sch]
2025-05-10 Updated schematic to get around XIAO pin restrictions
    [schematic-xiao.kicad_sch]
2025-05-12 perf: optimize WiFi and streaming performance
    Hardware:
    - Switch target board from ESP32-C3-DevKit-M to Seeed XIAO ESP32C3
    WiFi Optimizations:
    - Tune WiFi buffer sizes and queue lengths
    - Enable AMPDU for both RX and TX
    - Set RX/TX queue sizes (20/5)
    - Configure dynamic buffer numbers (RX: 16, TX: 16)
    - Set RX BA window to 6
    - Set max burst size to 8
    - MTU configuration has NOT been used
    Build Optimizations:
    - Add release profile with speed optimization (opt-level = 3)
    - Enable LTO for better performance
    - Disable debug symbols in release builds
    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
    [schematic-xiao.kicad_sch]
2025-05-12 LED shows when all has been initialised
2025-05-14 LED indicates when wifi has been connected
2025-05-30 Solved lack of memory problem
    [lib.rs, main.rs]
2025-06-02 Sketch of rotary encoder 'one-pin' board
    [rotary-encoder.kicad_pcb, rotary-encoder.kicad_sch]
2025-06-03 M3U reading kind of works, but still errors
    [lib.rs]
2025-06-09 Protoboard layout
    [button_board.kicad_pcb, button_board.kicad_sch, rotary-encoder.kicad_sch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]
2025-06-09 Removing changes for later overwrite
    [button_board.kicad_pcb, button_board.kicad_sch]
2025-06-09 Button board design
    [button_board.kicad_pcb, button_board.kicad_sch]
2025-06-10 Removed panics, error messages etc.
    [lib.rs]
2025-06-14 Button board hardware design
    [button_board.kicad_pcb, button_board.kicad_sch]
2025-06-22 Corrected error with fn button_pressed
    [front_panel.rs]
2025-06-23 Preset buttons work (without interrupt logic)
    [button_board.kicad_pcb, button_board.kicad_sch, schematic-xiao.kicad_sch]
2025-06-23 Rotary encoder wiring consistent with bitton-board
    [schematic-xiao.kicad_sch]
2025-06-30 Can read the rotary encoder
2025-06-30 Added notes for future development
    [schematic-xiao.kicad_sch]
2025-07-02 Current station handling
2025-07-02 Rotary encoder works, but is unreliable!
2025-07-06 Added station indicator LED control
2025-07-08 Corrected preset positioning problem
    [lib.rs, mod.rs]
2025-07-25 Upgraded - only the driver locking needs to be modified.
2025-07-29 Reverting back to the locked driver technique
    [hardware.rs, main.rs, mod.rs]
2025-07-29 Sendable abapter for the mcp23s17 driver
2025-08-28 Display added to schematic + RESET_CODEC + R_SW_PU symbol
    [schematic-xiao.kicad_sch]
2025-08-28 Wiring changes to RESET_CODEC
    [hardware.rs, main.rs]
2025-08-30 Rejected using 5V for display + comments
    [schematic-xiao.kicad_sch]
2025-09-25 Added display SPI isolator
    [schematic-xiao.kicad_sch]
2025-10-01 5V power for display
    [schematic-xiao.kicad_sch]
2025-10-01 Reducinng the SPI frequency for the multiplexer
2025-10-02 Added ra8875 driver
2025-12-03 Corrected the initialization order (particularly for wifi)
    [hardware.rs, main.rs]
2025-12-05 Added todo note
    [schematic-xiao.kicad_sch]
2025-12-30 UART command design
2025-12-30 Added SPI bus, UART communication and seperate display processor
    [schematic-xiao.kicad_sch]
2026-01-18 Added xiao esp32-S3 symbol to project library
2026-01-23 Compiles for esp32s3 (xtensa architecture)
2026-01-23 Radio works with esp32s3! But cannot change stations
2026-01-26 Correctly displays tuned station
    [mod.rs]
2026-02-20 Set correct target for xtensa-esp32s3-none-elf
    [main.rs]
2026-03-20 Changed signal names from display to ui
    [schematic-xiao.kicad_sch]
2026-03-20 Rewired for 2 processors - one for radio, the other for UI
    [schematic-xiao.kicad_sch]
2026-03-20 Updated schematic page settings
    [schematic-xiao.kicad_sch]
2026-04-02 Migration to C3 and front panel removal completed
    [schematic-xiao.kicad_sch]
2026-04-09 Finished ESP32-C3 migration
2026-04-11 Added uart-handler. Removed profile.
2026-04-11 Added uart-handler
2026-04-11 Basic skeleton for uart-handler
2026-04-15 Removed function send_hallo as no longer required
    [lib.rs, uart_handler_tests.rs]
2026-04-15 Refactored into the struct UartHandler
2026-04-17 Moved command tests to uart_handler tests
2026-04-18 Added generic constants to uart_handler
2026-04-18 Replaced Command::stringify with From trait and directly converted to bytes
    [uart_handler.rs, uart_handler_tests.rs]
2026-04-26 Remove all uart logic as the approach was not working
2026-06-03 Set up UART
2026-06-06 Removed the unnecessary wraping of Uart in a Mutex
2026-06-06 Updated uart_handler with function send_ack and send_error, i.e. receiver side functions
2026-06-16 Refactored and removed the mutex on uart
2026-06-21 Set up new pub/sub framework and display task.
2026-06-22 Skeleton uart mock
2026-06-25 Partially functioning mock-uart
2026-10-15 Added UART Timeout and refactored TunerEvents to TunerEvent for consistency across modules
2026-11-09 Added capacitors to inhibit brownout restarts
